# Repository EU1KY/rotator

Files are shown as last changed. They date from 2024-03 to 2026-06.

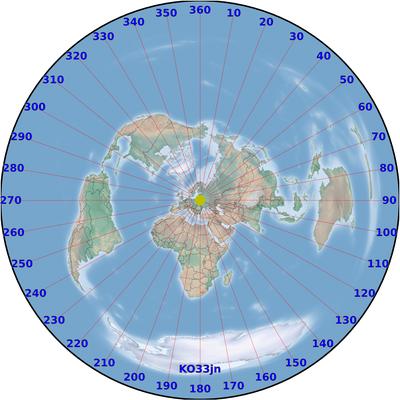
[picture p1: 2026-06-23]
static/azmap_s.jpg

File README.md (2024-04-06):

# Building a ESP32 based antenna rotator controller

This is just a preliminary description.

Hardware required:
- ESP-WROOM-32 Devkit board. If the device will be mounted in a metallic enclosure, ESP32-WROOM-32U Devkit is recommended with
external WiFi antenna and U.FL pigtail.
- AS5600 azimuth encoder board
- NEMA23 stepper motor with 8mm shaft (56mm/2.8A is suitable, lightweight and compact) 
- 6600 type stepper motor driver, or similar, that supports 1/8 substeps
- NMRV 030 worm gearbox 1:50, with a compatible 14mm single output shaft, and an input sleeve for 8mm NEMA23 shaft.

The code is working under Micropython environment flashed to the ESP32 board.

All configuration is in the config.py file. A custom azimuth map can be placed as a rotator's web gauge background, it can be
created with the online tool at https://ns6t.net/azimuth/ , then properly cropped as a square bitmap and saved as a 400x400 pixels image file in static/azmap_s.jpg .

Alternatively, use the included azmap_gen/azmap_gen.py Python script to generate azimuthal map file for your QTH locator. It looks much better.

The only wiring to the rotator is just a power supply (14 Volts 1A max is enough), it then connects to the preconfigured WiFi
network and appears as a web server in your LAN.

Rotator is controlled remotely with a web interface running on ESP32 under the Microdot web server. The interface uses websockets
for live updates and command submissions. This is how the web interface is displayed in my browser:



There is a FTP server that runs in the background. The updated python and HTML/CSS files can then be uploaded with a convenient FTP client,
even with Windows Explorer. Thus, on-the-air code updating is possible. The device automatically resets after FTP client disconnection
to apply changes. But be careful: if your files have critical bugs, the device can be bricked and you will need to put the antenna down
to connect to the device directly for recovery. Be especially careful when updating the boot.py and config.py files. 

My current working prototype:

prototype_1
prototype_2
prototype_3

Здесь черновик подробной инструкции, что и как делать, пока только на русском: https://github.com/EU1KY/rotator/wiki

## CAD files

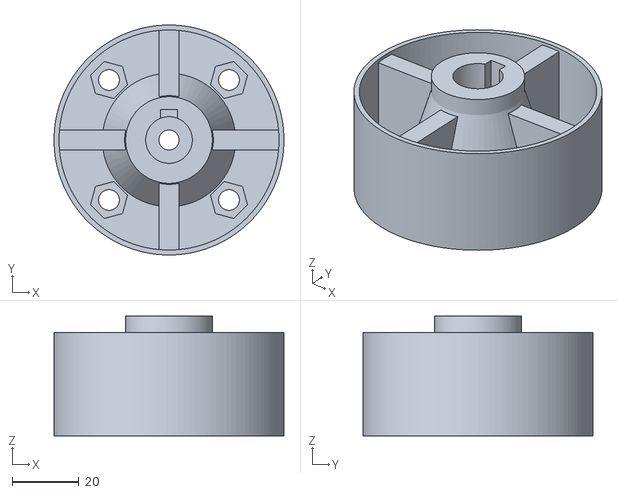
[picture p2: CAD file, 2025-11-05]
3d_parts/Flange_with_drip_edge_for_gasket.stl
69.0 x 69.0 x 36.0

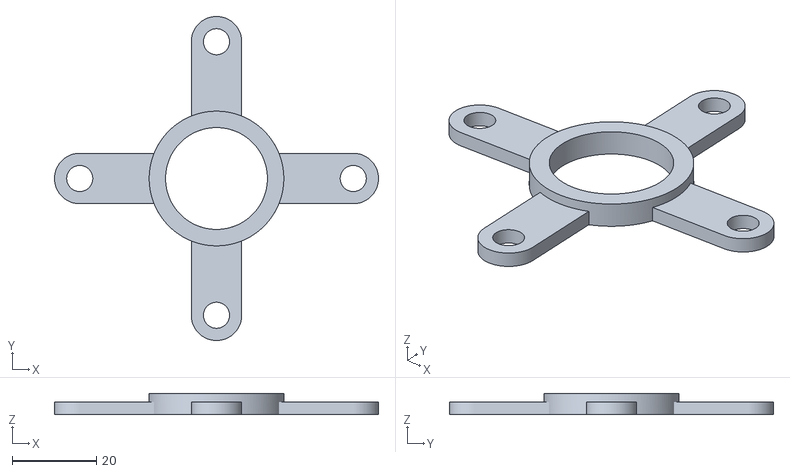
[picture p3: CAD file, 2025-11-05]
3d_parts/gasket_14x24x5_holder.stl
77.0 x 77.0 x 5.00

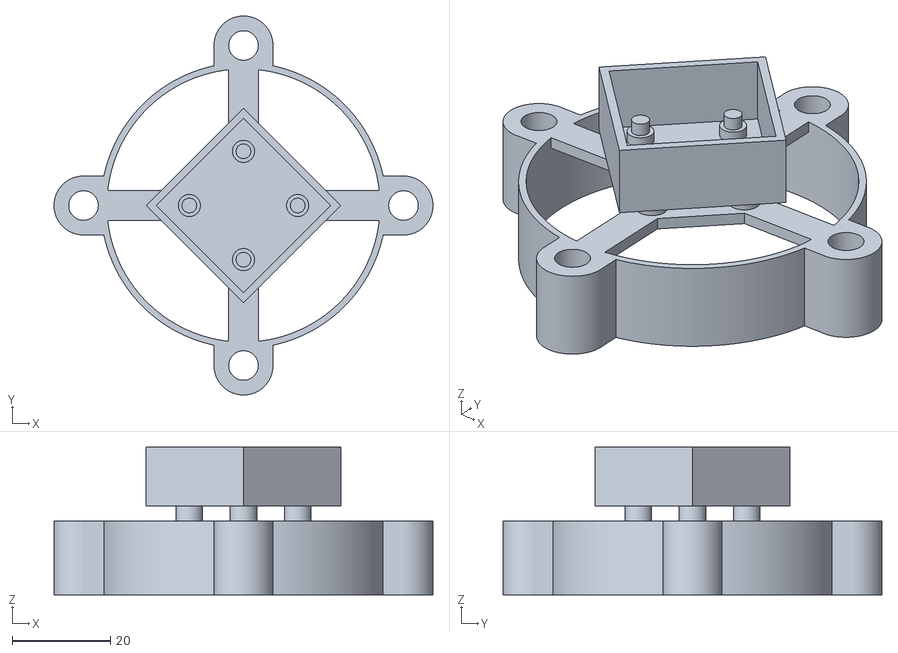
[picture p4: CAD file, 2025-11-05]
3d_parts/AS5600_holder_sealed.stl
77.0 x 77.0 x 30.0

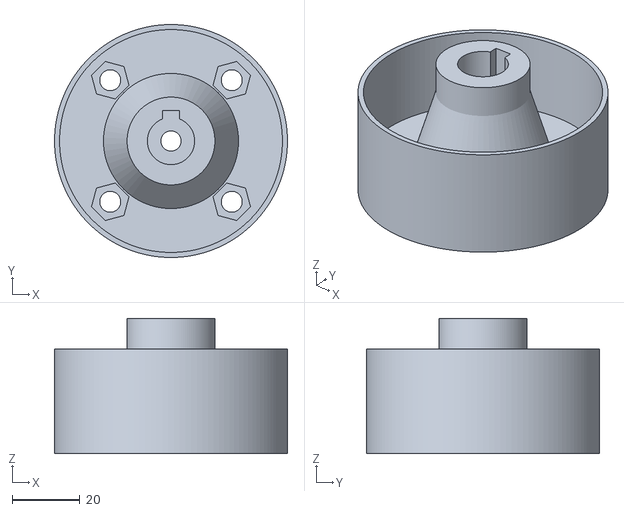
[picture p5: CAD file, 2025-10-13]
3d_parts/Flange_with_drip_edge.stl
69.0 x 69.0 x 40.0

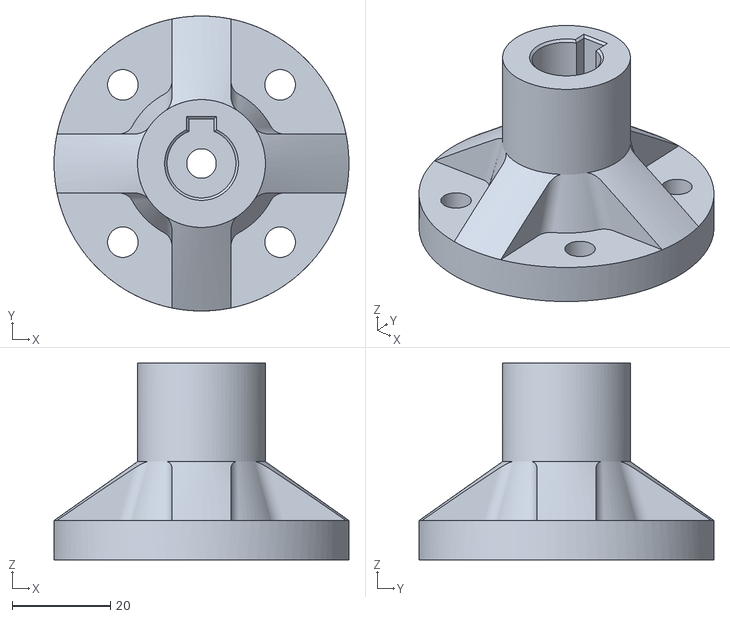
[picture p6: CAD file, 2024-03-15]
3d_parts/enforced_flange_by_RK9AMX.stl
60.0 x 60.0 x 40.0

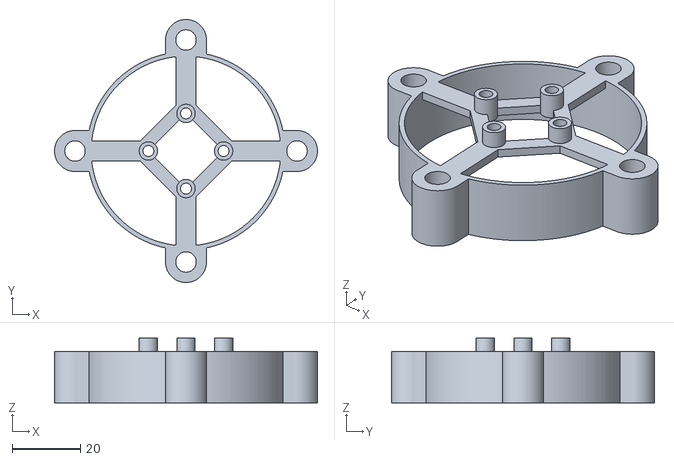
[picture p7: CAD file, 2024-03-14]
3d_parts/AS5600_holder.stl
77.0 x 77.0 x 19.0

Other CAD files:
3d_parts/Output_flange.stl

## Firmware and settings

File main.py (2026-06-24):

from machine import I2C, Pin, PWM
from microdot_asyncio import Microdot, Response, send_file
from microdot_utemplate import render_template
from microdot_asyncio_websocket import with_websocket
import uasyncio as asyncio
from config import RotatorConfig as CFG

azimuth = -1
target = -1

correction = CFG.AZ_CORRECTION
pwmPin = Pin(CFG.PWM_PIN)
dirPin = Pin(CFG.DIR_PIN, Pin.OUT)
enPin = Pin(CFG.EN_PIN, Pin.OUT)
DIRCW = CFG.DIRCW
DIRCCW = CFG.DIRCCW
ROTENABLE = CFG.ROTENABLE
ROTDISABLE = CFG.ROTDISABLE
FREQ_LO  = CFG.FREQ_LO
FREQ_MID = CFG.FREQ_MID
FREQ_HI = CFG.FREQ_HI
ROT_THRESHOLD_HI = CFG.ROT_THRESHOLD_HI
ROT_THRESHOLD_LO = CFG.ROT_THRESHOLD_LO

try:
    AZ_MAX = CFG.AZ_MAX
    AZ_MIN = CFG.AZ_MIN
except:
    AZ_MAX = 357
    AZ_MIN = 2

enPin.value(ROTDISABLE)

# Initialize MicroDot
app = Microdot()
Response.default_content_type = 'text/html'
i2c = I2C(0, scl=Pin(CFG.I2C_SCL_PIN), sda=Pin(CFG.I2C_SDA_PIN), freq=400000)


# root route
@app.route('/')
async def index(request):
    return render_template('index.html', rotatorname = CFG.HOSTNAME + " " + station.ifconfig()[0])


@app.route('/ws')
@with_websocket
async def read_sensor(request, ws):
    #print("read /ws")
    global azimuth
    global target
    while True:
        data = await ws.receive()
        try:
            tmp = int(data)
            if tmp >= -1:
                if tmp > AZ_MAX:
                    tmp = AZ_MAX
                elif tmp < AZ_MIN:
                    tmp = AZ_MIN
                target = tmp
            else:
                target = -1
        except:
            if data == 'cw':
                target = -1
                await asyncio.sleep(0.2)
                target = -2
                dirPin.value(DIRCW)
                tmppwm = PWM(pwmPin, freq=FREQ_LO, duty=512)
                enPin.value(ROTENABLE)
                await asyncio.sleep(1.0)
                tmppwm.deinit()
                enPin.value(ROTDISABLE)
                target = -1
            elif data == 'ccw':
                target = -1
                await asyncio.sleep(0.2)
                target = -2
                dirPin.value(DIRCCW)
                tmppwm = PWM(pwmPin, freq=FREQ_LO, duty=512)
                enPin.value(ROTENABLE)
                await asyncio.sleep(1.0)
                tmppwm.deinit()
                enPin.value(ROTDISABLE)
                target = -1
        await ws.send(f'{{ "azimuth" : {azimuth}, "target" : {target} }}')


# Static CSS/JS
@app.route("/static/<path:path>")
def static(request, path):
    if ".." in path:
        # directory traversal is not allowed
        return "Not found", 404
    return send_file("static/" + path)


async def update_az():
    global azimuth
    #Read raw angle
    while True:
        try:
            bytes = i2c.readfrom_mem(0x36, 0xC, 2)
        except:
            azimuth = -1
            #print("read error")
        else:
            rawangle = int.from_bytes(bytes, 'big') & 0xFFF
            tazimuth = round(rawangle * 360 / 4096)
            if CFG.AS_DIR_INVERT:
                tazimuth = 360 - tazimuth
            tazimuth += correction
            if tazimuth >= 360: tazimuth -= 360
            elif tazimuth < 0: tazimuth += 360
            azimuth = tazimuth
            #print(f"{azimuth=}")
        await asyncio.sleep(0.1)


async def pwm_proc():
    global target
    global azimuth
    outpwm = None
    while True:
        while target == -2: #forced rotation is in progress
            await asyncio.sleep(0.1)
        if target != -1:
            if azimuth == -1 or target == azimuth:
                target = -1
            else:
                #print(f"{azimuth=}, setting up for {target=}")
                target_s = target
                if target_s < azimuth:
                    dirPin.value(DIRCCW)
                    dir = DIRCCW
                    #print("Dir=CCW")
                else:
                    dirPin.value(DIRCW)
                    dir = DIRCW
                    #print("Dir=CW")
                frequency = FREQ_LO
                outpwm = PWM(pwmPin, freq=frequency, duty=512)
                #print(f"{frequency=}")
                enPin.value(ROTENABLE)
                #print("En=On")
                rot_diff = max(target_s, azimuth) - min(target_s, azimuth)
                if rot_diff >= ROT_THRESHOLD_HI: #Start at slow speed
                    await asyncio.sleep(1)
                while True:
                    await asyncio.sleep(0.02)
                    if target_s != target:
                        #print("Target has changed")
                        break
                    if ( target_s == azimuth or
                         (dir == DIRCW and target_s < azimuth) or
                         (dir == DIRCCW and target_s > azimuth) ):
                        #print("Azimuth reached the target")
                        target = -1
                        break
                    rot_diff = max(target_s, azimuth) - min(target_s, azimuth)
                    if rot_diff < ROT_THRESHOLD_LO:
                        if frequency != FREQ_LO:
                            frequency = FREQ_LO
                            outpwm.freq(frequency)
                            #print(f"upd {frequency=}")
                    elif rot_diff < ROT_THRESHOLD_HI:
                        if frequency != FREQ_MID:
                            frequency = FREQ_MID
                            outpwm.freq(frequency)
                            #print(f"upd {frequency=}")
                    else:
                        if frequency != FREQ_HI:
                            frequency = FREQ_HI
                            outpwm.freq(frequency)
                            #print(f"upd {frequency=}")
        if outpwm:
            enPin.value(ROTDISABLE)
            #print("En=Off")
            outpwm.deinit()
            outpwm = None
        await asyncio.sleep(0.1)


async def server_main():
    await app.start_server(port=80, debug=False)


async def __main():
    tasks = [server_main(), update_az(), pwm_proc()]
    ret = await asyncio.gather(*tasks)


if __name__ == "__main__":
    try:
        asyncio.run(__main())
    except KeyboardInterrupt:
        pass
    gc.collect()
    print("Exit main.py")

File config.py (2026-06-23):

class RotatorConfig:
    WIFI_SSID = 'Your_WiFi_SSID'
    WIFI_PASSWD = 'Your_WiFi_password'
    HOSTNAME = 'rotator'  # mDNS name of the rotator in the WiFi network
    AZ_CORRECTION = -6
    PWM_PIN = 4
    DIR_PIN = 16
    EN_PIN = 17
    DIRCW = 0         #Clockwise rotation polarity value
    DIRCCW = 1        #Counter-clockwise rotation polarity value
    ROTENABLE = 0     #Rotation enable polarity value
    ROTDISABLE = 1    #Rotation disable polarity value
    FREQ_LO  = 500
    FREQ_MID = 1000
    FREQ_HI = 2000
    ROT_THRESHOLD_HI = 15
    ROT_THRESHOLD_LO = 7
    I2C_SCL_PIN = 22
    I2C_SDA_PIN = 21
    AS_DIR_INVERT = 0  # 0 or 1 depending on AS5600 DIR pin connection
    AZ_MIN = 2          # Minimum azimuth, degrees
    AZ_MAX = 357        # Maximum azimuth, degrees

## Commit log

2024-03-15 Added reset on FTPclient disconnection
    [uftpd.py]
2024-03-15 Added enforced flange 3D model by RK9AMX
    [enforced_flange_by_RK9AMX.stl]
2024-04-05 Improved the target reach detection logic to consider a possible overshooting
    [main.py]
2025-10-13 feat: Added AS5600 DIR pin inversion
2025-10-13 feat: Added a flange 3D model with drip edge
    [Flange_with_drip_edge.stl]
2025-11-05 feat: added 3D models for 14x24x5 gasket
    [AS5600_holder_sealed.stl, Flange_with_drip_edge_for_gasket.stl, gasket_14x24x5_holder.stl]
2025-11-05 fix: added missing file
    [Flange_with_drip_edge_for_gasket.stl]
2026-06-23 feat: Added buttons for short rotation pulses
2026-06-24 feat: Forced rotation buttons handling in websocket hook
